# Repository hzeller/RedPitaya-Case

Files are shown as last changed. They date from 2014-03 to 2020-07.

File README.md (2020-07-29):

A case for the RedPitaya
------------------------

A shielded case for the scope/function generator instrument from
http://redpitaya.com/.
The bare RedPitaya is just the board and without any shielding or protective
housing - this project attempts to remedy that.
An older version of this I also have on [YouMagine][youmagine-design]
(also thingiverse 278113).

### Parts
The `shield-metal-cut.ps` PostScript file is the source for the shielding.
Print this on paper, glue on a thin (best tinned) iron shield metal (like from an old consumer device or something like a can with flat tinned metal, e.g. an empty paint thinner can) and cut out.
Make sure that your printer program output is scaled 1:1 (some PDF readers add
a margin to the page and scale the rest).
The PostScript program is hand-written, so easy to modify (essentially
poor-mans parametric 2D CAD :) ).
If you notice that your printer does not scale the output properly (there is
a line of reference length in the printout), you can correct that directly in the
program, just change the actual length in the [`/measured-reference-length`][reference-len]
variable.

If you need a DXF file, create shield-metal-cut.dxf with the Makefile (`make shield-metal-cut.dxf`). Documentation text is written in blue and shows up as
separate channel in the DXF.

Top                                   | Bottom
--------------------------------------|------------------------------------
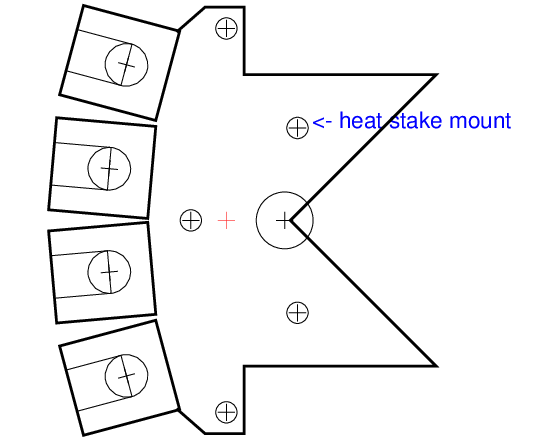
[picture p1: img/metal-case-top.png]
Top Case
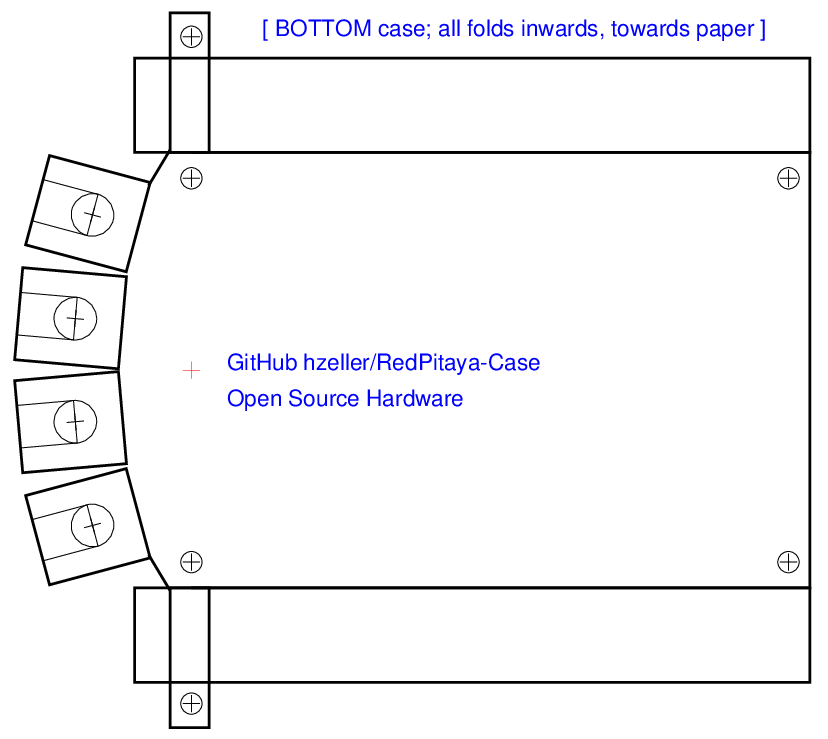
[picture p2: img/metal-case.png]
Metal Case
 | 

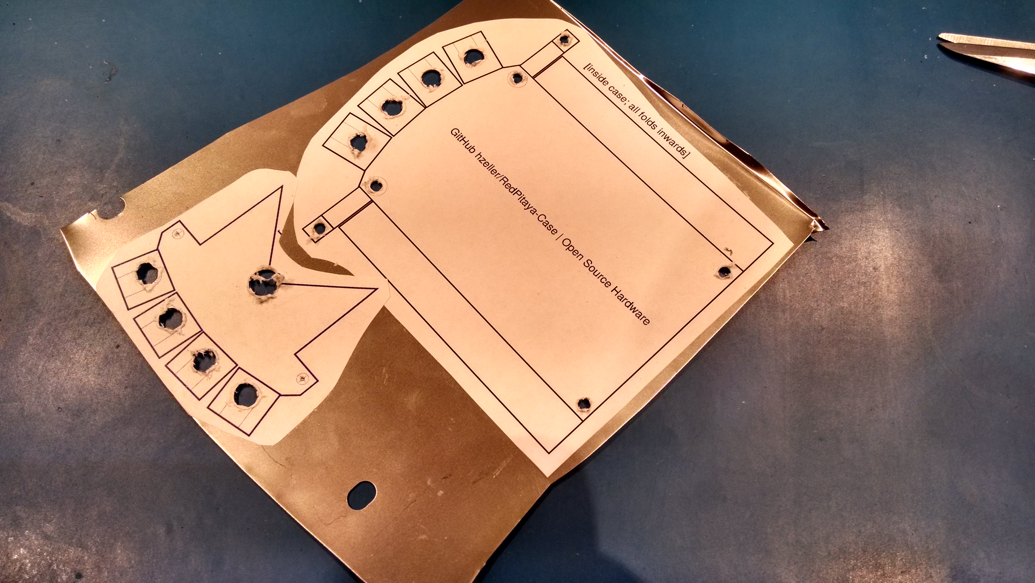
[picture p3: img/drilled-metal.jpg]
Physical


The OpenScad file plastic-case.scad is the source for the 3D objects and the
Makefile creates the STLs to print
These are the stand-offs ([`fab-print_standoffs.stl`](./fab-print_standoffs.stl)) and the actual case ([`fab-print_case.stl`](./fab-print_standoffs.stl)); these
files are created using the Makefile and OpenSCAD, but are are included in
this distribution for easy use.

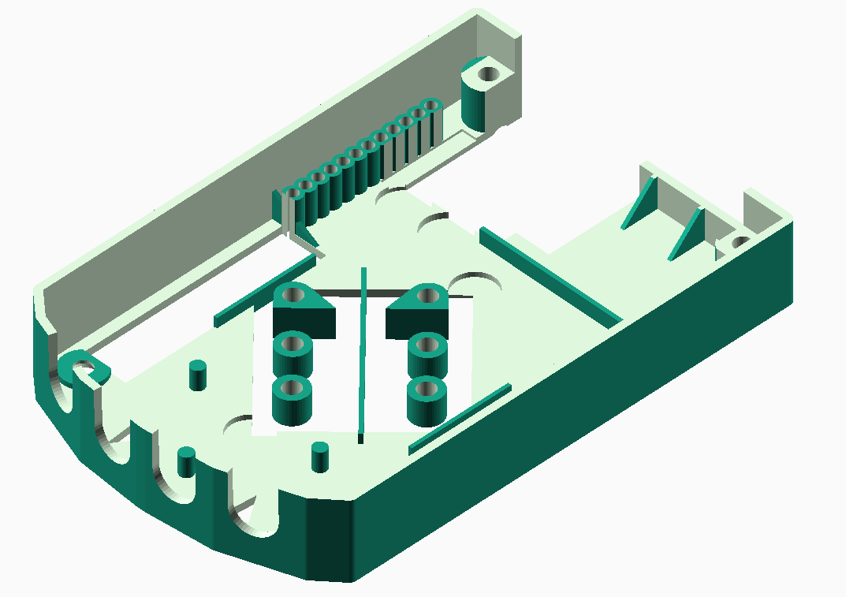
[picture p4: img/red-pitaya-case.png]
3D Print


### Assembly

#### Top Shielding
Use a center punch to mark the drill holes in the sheet metal.
Drill the holes - 3mm for screw-mounts, 8mm for SMA connectors and
around the heatsink mount.

Now cut out the shape, if you have thin enough material, a scissor should work just fine. Bend with pliers (there are instructions in which direction on the printout).

The top part of the shield will be attached with plastic heat staking: place
the top shield part on the case on the inside and make sure that it fits (the
connection across the heatsink pokes a bit into its space, cut that out).
If it fits nicely, the three plastic pins should fit through the holes and the
mounting holes right and left should align with the hole in the case.
Press down the metal and melt the plastic pins by pressing a soldering iron
on top - let cool. Now the top shielding is permanently in place. Put a bit of
electrical tape above where the jumpers are to avoid that they make accidental
contact.

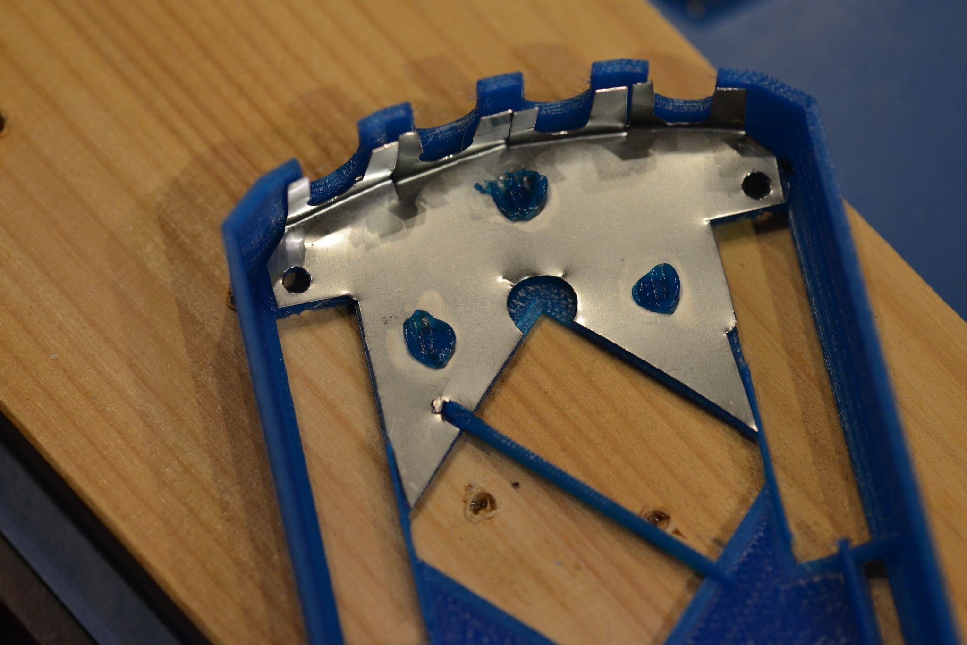
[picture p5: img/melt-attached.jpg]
Attached with heat-stake


#### Bottom Shielding

The large bottom shielding is also the bottom of the case.

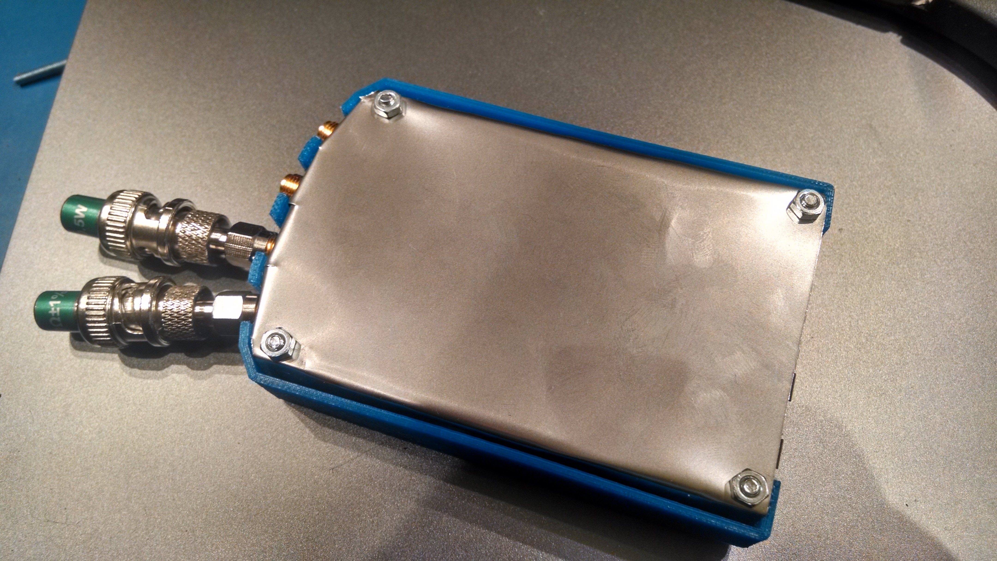
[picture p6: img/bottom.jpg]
Assembled unit bottom


Place the round stand-offs on the inside of your metal shield case (gluing them
in place with superglue on the metal case is a good idea, so that they don't
annoy you by falling out when needed).

The top spacers in the front is a bit triangular shaped, so that it is
possible to glue them against the 13x2 connector .. that way, you don't
have to put glue on the board itself.

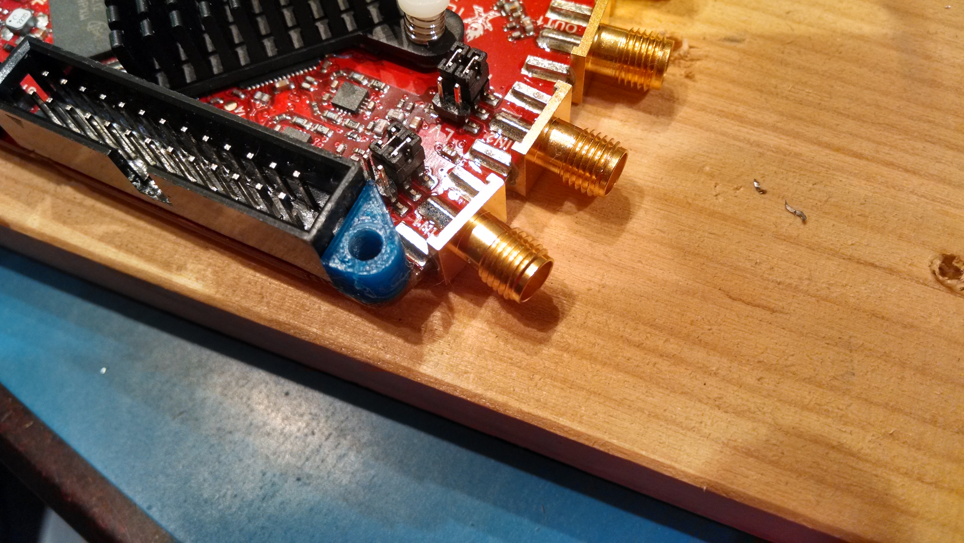
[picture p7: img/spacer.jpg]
spacer


Place the RedPitaya in the bottom case, with the mounting holes sitting on
top of the stand-offs (don't forget to remove the original standoffs that
come with the RedPitaya) and adjust the SMA-connector flaps if necessary.

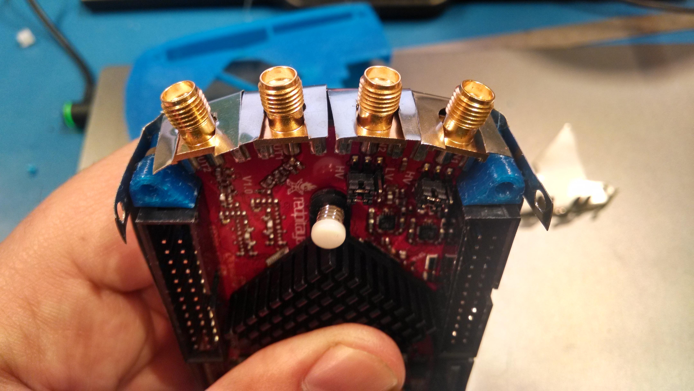
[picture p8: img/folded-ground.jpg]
SMA-flaps


Bend around the little screw-flaps (right and left in the image above) of the
metal case so that they sit on the triangular shaped stand-offs on top (this
might be a bit fiddely).
A good technique is -- while assembly -- to have screws push up from the
bottom of the case to have all assembly holes aligned. The screw flaps will
make sure the ground on the top case is properly connected.

If you want to really be sure of the grounding, you might want to solder a
little cable from the ground of one of the analog connectors and wrap it
around the screw hole or something, but the metal contact on the
SMA connectors should be sufficient (I didn't bother with the cable).

Before the final assembly: the case has some diagonal flaps between the connector cutouts on the long edge. For that to fit with the bottom metal shield, you need to cut out a little notch there (TODO: add to postscript file).

Place the top of the case on top of the assembly and push 20mm M3 countersunk
screws through all assembly holes. Fasten them with M3 nuts on the bottom.

#### Light Pipes

Once the case is put together, we can install the light pipes. These provide
a nice crisp view of the LEDs inside the case. They are
done by placing a piece of transparent 3D print filament in the holes (in
this case some transparent 1.75mm PETG filament - this is a very clear
filament). Just poke it into the opening until
it hits the LED below, then trim the top. The result is a very nice
sharply defined LED visibility.

Install      | Trimming | LED visibility
-------------|----------|-------------------------
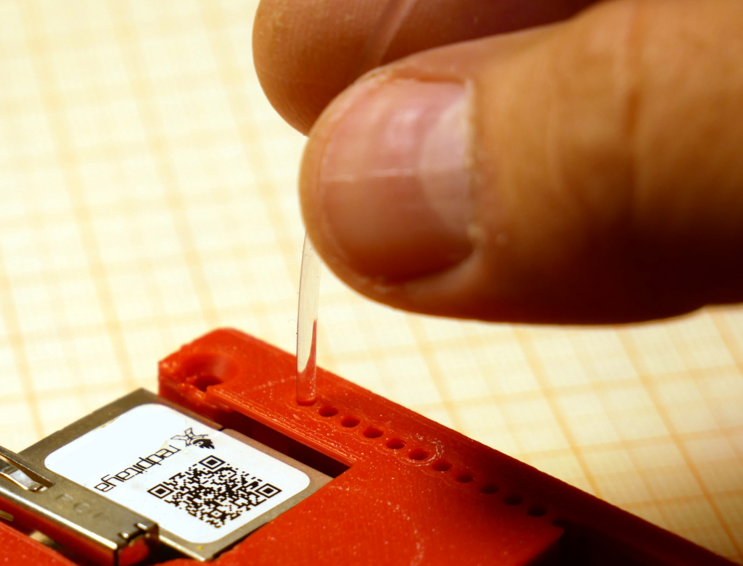
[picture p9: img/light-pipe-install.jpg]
Install
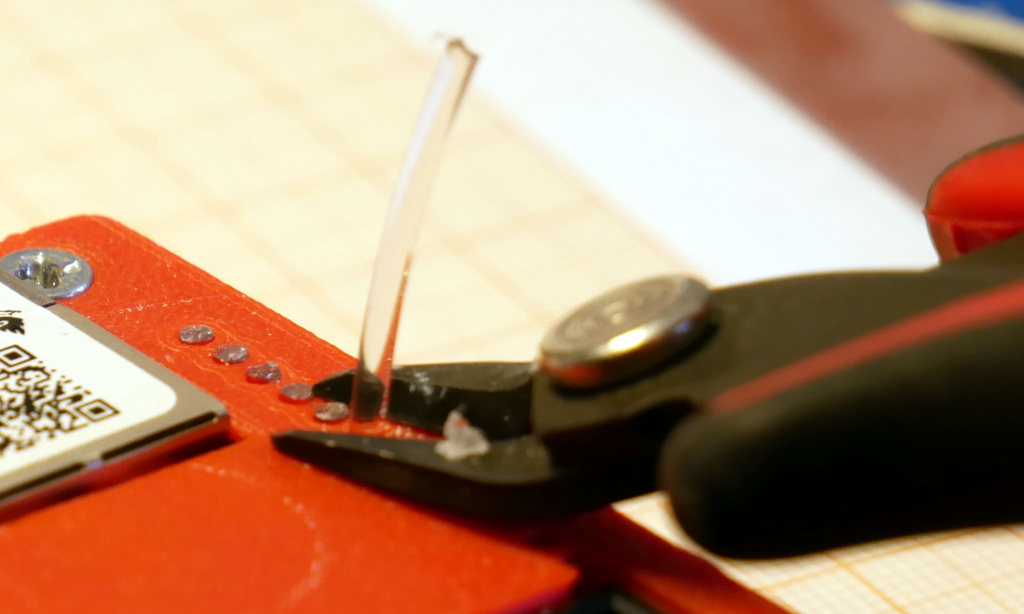
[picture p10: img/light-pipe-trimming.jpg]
Trim
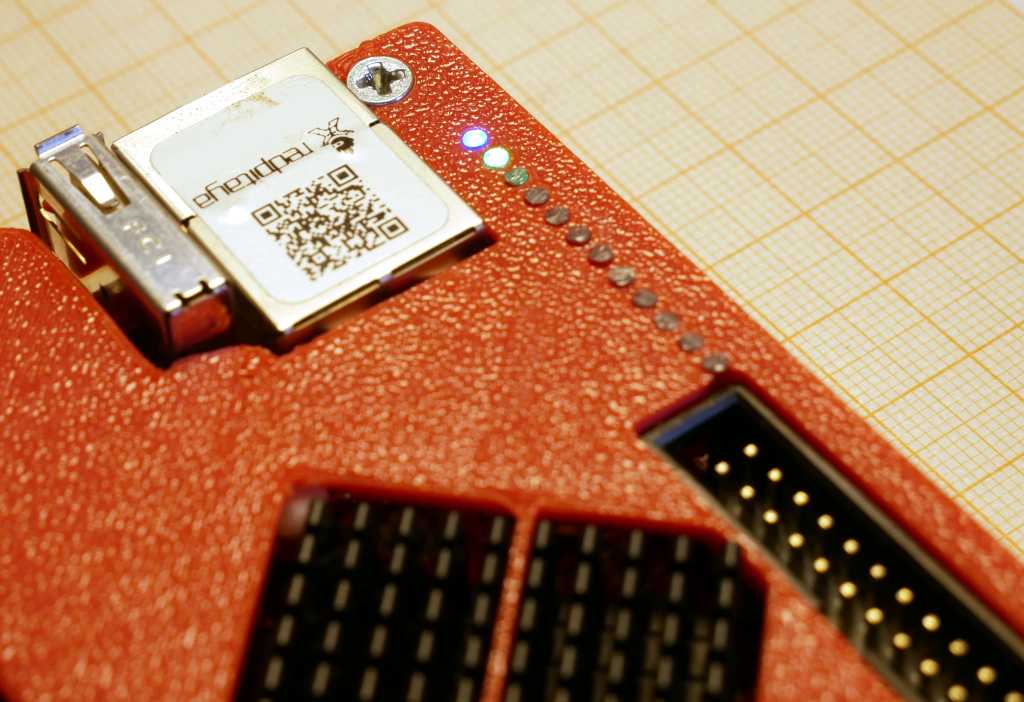
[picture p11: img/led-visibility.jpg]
Visibility
 |  | 

The final case looks like this; the arrows indicate input/outputs.
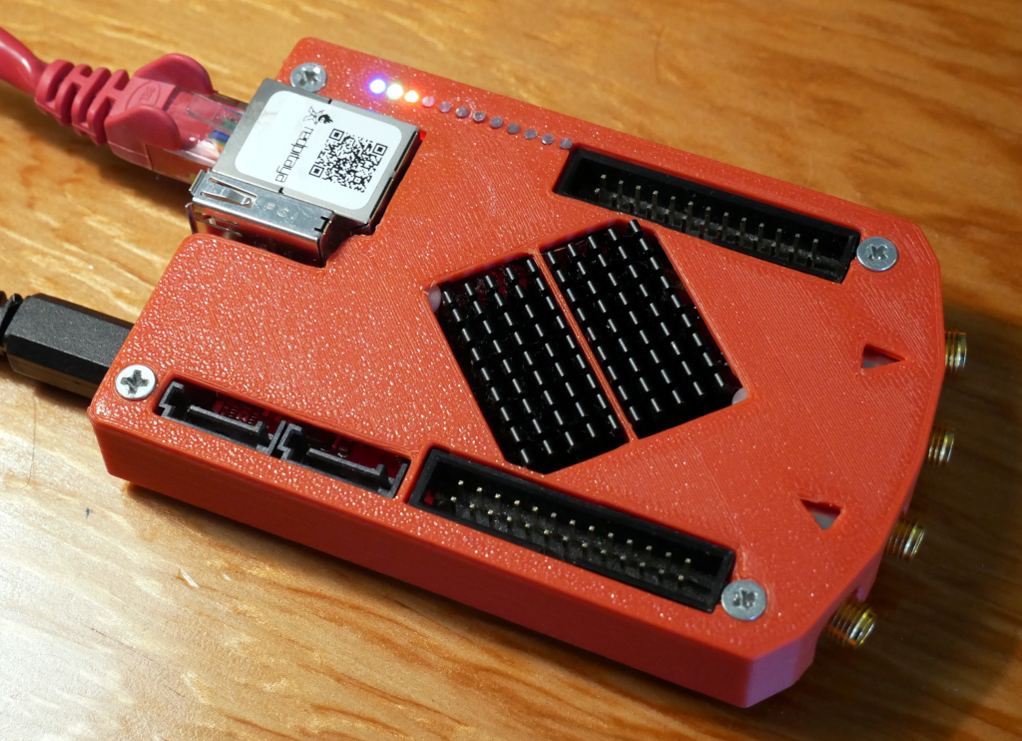
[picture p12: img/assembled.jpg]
Assembled unit


[reference-len]: https://github.com/hzeller/RedPitaya-Case/blob/master/shield-metal-cut.ps#L24
[metal-case]: ./img/metal-case.png
[melt-attached]: ./img/melt-attached.jpg
[assembled]: ./img/assembled.jpg
[design]: ./img/red-pitaya-case.png
[youmagine-design]: https://www.youmagine.com/designs/shielded-redpitaya-case
[thing278113]: http://www.thingiverse.com/thing:278113

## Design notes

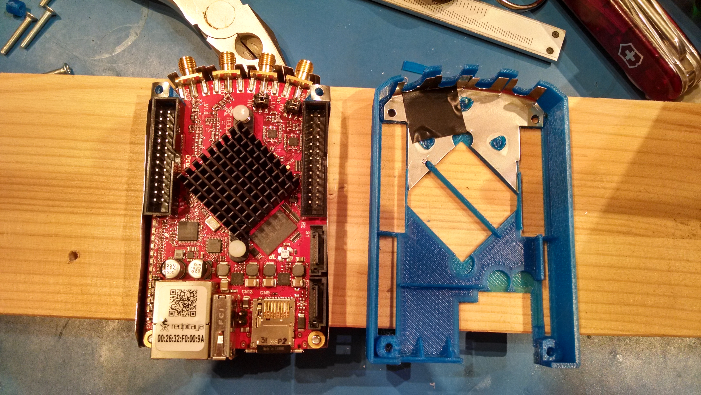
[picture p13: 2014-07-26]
img/ready-to-close.jpg

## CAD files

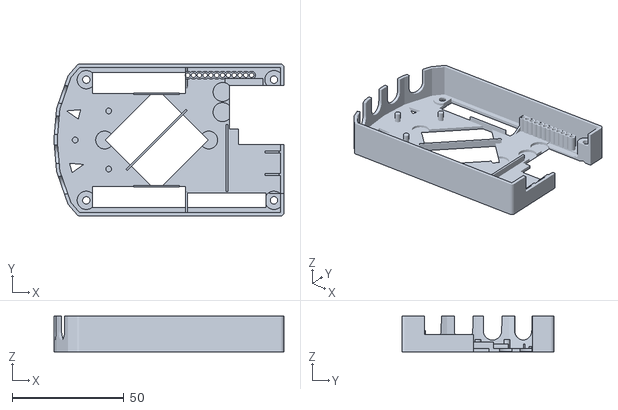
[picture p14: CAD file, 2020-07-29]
fab-print_case.stl
103.0 x 68.0 x 16.0

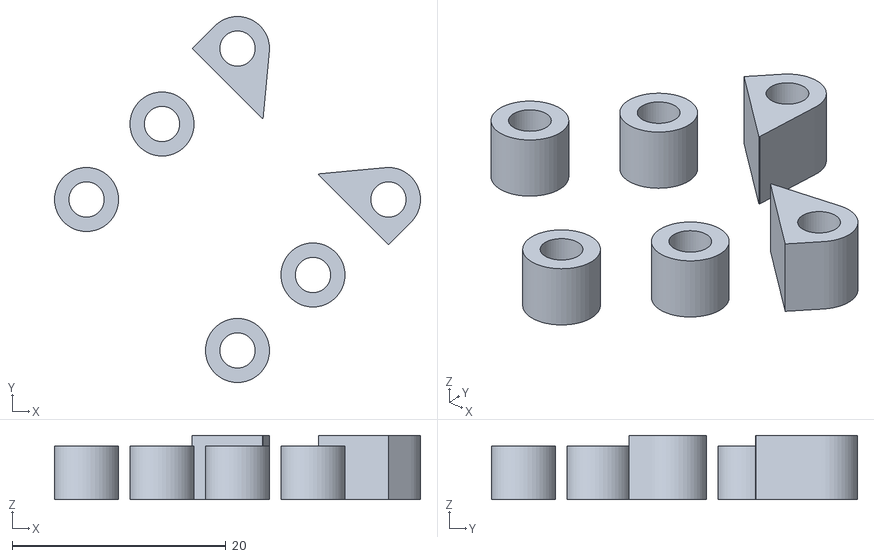
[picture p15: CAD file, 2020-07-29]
fab-print_standoffs.stl
34.3 x 34.3 x 6.00

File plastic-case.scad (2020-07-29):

// RedPitaya case
//(cc-BY-SA) h.zeller@acm.org
// Some measurements are a bit manually 'adjusted' - this should be more
// parametric. Ah, well, first version.
$fn=48;
epsilon=0.1;

case_thick=1.5;

// rounded: pretty for printing, but without much faster for development.
// Also, might create trouble with 'liftoff'
rounded=true;

stand_b=5;   // Standoff bottom
stand_t=6;   // Standoff top (above board, below shield)

mechanical_support=0.8;

screw_head_dia=6;
screw_head_thick=2;
screw_base_dia=8.2;

base_headroom=1;
shield_mount_thick=1;  // The thickness of the two shielding flaps on top of each other.
board_thick=1.65;
above_shield=stand_b + board_thick + stand_t + shield_mount_thick;

base_t=above_shield + base_headroom;
base_w=90;
base_h=65;

drill_hole=3 + 0.3;

connector_height=9.3;

heatsink_extra_space=4;  // Additional space around edges of the heatsink.

// Lightpipe.
light_distance=2.6;
light_diameter=1.85+0.2;
light_outer=3.5;

// The standoff in the corner of the analog area. With
// one flat area, so that it is possible to tempoarily fix
// it to the 13x2 connector while assembling.
module analog_corner_standoff() {
    difference() {
	hull() {
	    cylinder(r=stand_t/2, h=stand_t);
	    translate([-connector_height + stand_t/2, -stand_t/2, 0]) cube([connector_height, 0.1, stand_t]);
	}

	// bore hole.
	translate([0,0,-epsilon]) cylinder(r=drill_hole/2, h=stand_t + 2 * epsilon);
    }
}

module bottom_standoff() {
    difference() {
	cylinder(r=stand_t/2, h=stand_b);
	translate([0,0,-epsilon]) cylinder(r=drill_hole/2, h=stand_t + 2 * epsilon);
    }
}

module led_pipes(punch=false) {
     for (i = [0:1:11]) {
	  translate([i*light_distance, 0, 0]) {
	       if (punch) {
		    cylinder(r=light_diameter/2, h=15);
	       } else {
		    translate([0, 0, 5]) cylinder(r=light_outer/2, h=10);
	       }
	  }
     }
}

// Put together the set of standoffs needed.
module standoffs() {
    translate([-10, 10, 0]) mirror([1,0,0]) analog_corner_standoff();
    translate([10, 10, 0]) analog_corner_standoff();
    translate([-10, 0, 0]) bottom_standoff();
    translate([10, 0, 0]) bottom_standoff();
    translate([-10, -10, 0]) bottom_standoff();
    translate([10, -10, 0]) bottom_standoff();
}

// Parts mounted on the RedPitaya
module connector13x2() {
    color("DarkSlateGray") cube([40.6 + 2 * 0.5, 8.8 + 2 * 0.3, connector_height + 1]);
}
module ethernet() {
    // we go 'underground' as we need to poke space into the case
    color("silver") translate([0, 0, -8]) cube([25, 19.5, 11.3 + 8]);
}
module usb() {
    color("silver") translate([0, 0, -8]) cube([21, 7.5, 14.5 + 8]);
}
module sata() {
    color("DarkSlateGray") cube([35, 6.5, connector_height + 1]);
}
module heatsink() {
    color("DarkSlateGray") rotate([0, 0, -45]) translate([0, 0, 10]) {
	difference() {
	    cube([28.5 + heatsink_extra_space, 28.5 + heatsink_extra_space, 20], center=true);
            // Some support through the fins
	    translate([0, 0, 2]) cube([30 + heatsink_extra_space, 0.8, 16], center=true);
	}
    }
    translate([-23.3, 0, 0]) cylinder(r=4, h=9);
    translate([+23.3, 0, 0]) cylinder(r=4, h=9);
}

module bnc_cut(radius=4.2) {
    hull() {
	rotate([0, 90, 0]) cylinder(r=radius, h=15);
	translate([0, -4, -15]) cube([15, 2 * radius, 1]);
    }
}
module arrow() {
    cylinder(r=2.5, h=30, $fn=3);
}

// The rough outline of the RedPitaya, so that we can substract its volume from the
// case and thus punch the holes for connectors and heatsink.
module RedPitaya() {
    translate([87, 0, board_thick]) rotate([0, 0, 180]) {
	// from Red_Pitaya_Dimensions_v1.0.1.pdf. All measuremeents are from the back of the board
	// so that is what we're using as reference (later we need to shift that, as the rest of the
	// case assume zeor-X at the row of screws)
	difference() {
	    translate([0, -30, -board_thick]) color("red") cube([90, 60, board_thick]);
	    // screw holes.
	    translate([3, 27, -2 + epsilon])   cylinder(r=3/2, h=2);
	    translate([3, -27, -2 + epsilon])  cylinder(r=3/2, h=2);
	    translate([87, 27, -2 + epsilon])  cylinder(r=3/2, h=2);
	    translate([87, -27, -2 + epsilon]) cylinder(r=3/2, h=2);
	}

	// Show direction of input/output
	translate([92, 12, 0]) rotate([0, 0, 15]) scale([1.6, 1, 1]) arrow();
	translate([92, -12, 0]) rotate([0, 0, 180-15]) scale([1.6, 1, 1]) arrow();

	translate([43.1 - 0.5, 21.2 - 0.3, 0])    connector13x2();
	translate([43.1 - 0.5, -30 - 0.3, 0])     connector13x2();
	translate([6.6, -23.3 - 7, 0])   sata();
	translate([-2.2, 30 - 6 - 19, 0]) ethernet();
	translate([-2.2, -2, 0])    usb();
	translate([-5, -24, -10 + 1.7]) cube([10, 24, 10]);  // power, terminal, SD-card
	translate([55.5, 0, 0])       heatsink();

	// Capacitors
	translate([26, 12.5, 0]) color("silver") cylinder(r=8.5/2, h=9.2);
	translate([26, 21.5, 0]) color("silver") cylinder(r=8.5/2, h=9.2);

	translate([8, 30 - 5.6, 0]) cube([17, 3.1, 8.5]);  // JTAG
	translate([13, 29, 0]) led_pipes(true);

	translate([89, -5.5, 0])  rotate([0, 0, -5]) bnc_cut();
	translate([89,  5.5, 0])  rotate([0, 0, 5])  bnc_cut();
	translate([87, -17.5, 0]) rotate([0, 0, -15]) bnc_cut();
	translate([87,  17.5, 0]) rotate([0, 0, 15])  bnc_cut();
    }
}

// The volume the case is wrapped around.
module cased_volume() {
    hull() {
	// Basic inner volume.
	translate([-3, -base_h/2, 0]) cube([base_w, base_h, base_t]);

	// The angled 'blocks' sticking out.
	// inner.
	translate([-3, 0, 0]) hull() {
	     rotate([0, 0, -5]) translate([-10, 0, 0]) cube([10, 13, base_t]);
	    rotate([0, 0, 5]) translate([-10, -13, 0]) cube([10, 13, base_t]);

	    // outer
	    rotate([0, 0, 15]) translate([-11, -26, 0]) cube([10, 13, base_t]);
	    rotate([0, 0, -15]) translate([-11, 13, 0]) cube([10, 13, base_t]);
	}
    }
}

module heatsink_support() {
    extra_len = 1.41 * heatsink_extra_space;
    translate([87 - 55.5, 21.2 - 0.5, base_t - 1 + case_thick/2]) cube([15 + extra_len, 0.7, 2 + case_thick], center=true);
    translate([87 - 55.5, -21.2 + 0.5, base_t - 1 + case_thick/2]) cube([15 + extra_len, 0.7, 2 + case_thick], center=true);
}

// Negative volume inside the case. Essentially thec ased volume, but we
// leave a couple of support structures in there.
module inner_volume() {
    // We want some mechanical construction parts left behind, e.g.
    // the screw supports or some rigidity enhancements. So we cut this out
    // of the inside block, so that they remain after we substract it from the outer block.
    difference() {
	cased_volume();

	// screw support.
	translate([0, 27, above_shield]) cylinder(r=screw_base_dia/2, h=40);
	translate([0, -27, above_shield]) cylinder(r=screw_base_dia/2, h=40);
	translate([84, 27, stand_b + board_thick]) cylinder(r=screw_base_dia/2, h=40);
	translate([84, -27, stand_b + board_thick]) cylinder(r=screw_base_dia/2, h=40);

	// Shielding case heat-stake mounts. These go through holes in the
	// shield to permanently mount the shield in the case ... with a soldering iron.
	translate([-5, 0, base_t - 4]) cylinder(r=1.3, h=5);
	translate([10, 13, base_t - 4]) cylinder(r=1.3, h=5);
	translate([10, -13, base_t - 4]) cylinder(r=1.3, h=5);

	// Some bridges around the connectors and heatsink corner to improve stability.
	// The heatsink cuts away some corner here, so below in mount(), we add that again.
	heatsink_support();

	// Angled support flaps for the back of the case.
	// Around the  SD card
	translate([80, 5, base_t]) rotate([0, 45, 0]) cube([20, mechanical_support, 20]);
	translate([80, 15, base_t]) rotate([0, 45, 0]) cube([20, mechanical_support, 20]);

	// Angled supports between connectors and SATA/LED-slot
	translate([87 - 42.5, 40, 5]) rotate([45 + 15, 0, 0]) cube([mechanical_support, 20, 20]);
	translate([87 - 42.5, -40, 5]) rotate([45 - 15, 0, 0]) cube([mechanical_support, 20, 20]);

	// Bar behind ethernet and usb
	translate([63, 8, base_t - 1.5 + epsilon]) cube([mechanical_support, 30, 3], center=true);

	// Bar accross the heatsink.
	translate([87 - 55.5, 0, base_t - 2/2]) rotate([0, 0, -45]) cube([34 + heatsink_extra_space, 0.8, 2], center=true);

	// Shield around LEDs (very close to ethernet - should not interfere with JTag)
	// Disabled now, the light-pipe shroud should do more of this
	//translate([54, -26, base_t - stand_t/2]) cube([20, mechanical_support, stand_t], center=true);

	translate([87 - 13 - 11*2.6, -29, 3]) led_pipes(false);
    }
}

module raw_case() {
    difference() {
	minkowski() {
	    cased_volume();
	    if (rounded) {
		//sphere(r=case_thick);  // This gives trouble with 'liftoff' platform.
		translate([0, 0, -case_thick]) cylinder(r=case_thick, h=2*case_thick);
	    } else {
		cube([2*case_thick, 2*case_thick, 2*case_thick], center=true);
	    }
	}
	inner_volume();
    }
}

module screw_head(x, y) {
    translate([x, y, base_t + case_thick - screw_head_thick + epsilon]) cylinder(r1=drill_hole/2, r2=screw_head_dia/2, h=screw_head_thick);
}

module case() {
    difference() {
	raw_case();
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

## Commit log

2014-03-16 o Initial commit.
    [rpcase.scad]
2014-03-16 o Simplify screw-fold. o Add little flap around edge which was 'vulnerable' before. o Better calculate the top-flaps.
2014-03-16 o Add reference lines for print-scale testing.
2014-03-16 o Rename files to something more reasonable.
    [plastic-case.scad]
2014-03-20 o First shot at a case. Might need some tweaking.
    [plastic-case.scad]
2014-03-20 o Place standoffs in the heatsink space. o add support bar accross heatsink. o add side support bars between connectors.
    [plastic-case.scad]
2014-03-21 o Add some images.
    [plastic-case.stl]
2014-03-21 o Comment update
    [plastic-case.scad]
2014-03-21 o Some comment updates. o Heatsink support: add solidness..
    [plastic-case.scad]
2014-03-21 o Update stl with latest scad.
    [plastic-case.stl]
2014-03-21 o Make space around heatsink configurable. Make it a bit larger than before (2mm all around insetad of 0.5mm).
    [plastic-case.scad, plastic-case.stl]
2014-03-22 o add 'mounting plastic studs'.
    [plastic-case.scad]
2014-03-22 o update stl.
    [plastic-case.stl]
2014-03-22 o Make support around heatsink a bit thicker.
    [plastic-case.scad, plastic-case.stl]
2014-03-22 o update images. o widen drill holes a little bit. o widen BNC cutouts.
    [plastic-case.scad, plastic-case.stl]
2014-03-22 o add melt-joint image.
2014-03-22 o update stl file.
    [plastic-case.stl]
2020-07-24 Update README; don't use assign in scad; separate text with color.
    * Update README and show more of the metal shield images.
    * OpenSCAD: the 'assign()' call has been deprecated in the meantime,
    regular assign will work.
    * Metal shield cuts: separate the cut lines from documentation text
    with color.
    [plastic-case.scad]
2020-07-29 LEDs: add light pipes. Update README.
    Light pipes are providing a much nicer look than the previous
    simple cut-out.
    Augment the README with things I had written on YouMagine already,
    so that it is a stand-alone description of the assembly process.
    [fab-print_case.stl, fab-print_standoffs.stl, plastic-case.scad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]
